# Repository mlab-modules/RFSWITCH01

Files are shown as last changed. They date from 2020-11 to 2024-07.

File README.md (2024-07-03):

# RFSWITCH01 - RF switch

## Introduction

The RFSWITCH01 is an MLAB module that incorporates a pair of RF switches, specifically the [PE4259](http://www.psemi.com/pdf/datasheets/pe4259ds.pdf). from Peregrine Semiconductor. This module is designed to connect to a radio transceiver that has separate radio input and output. Thanks to the use of two switches, the module allows connecting two antennas. The individual switches are controlled by a simple digital input signal. With RFSWITCH01, a transceiver can work with the support of [MIMO 2x2](https://en.wikipedia.org/wiki/MIMO). The module is typically assembled for frequencies of 433MHz and 868MHz.

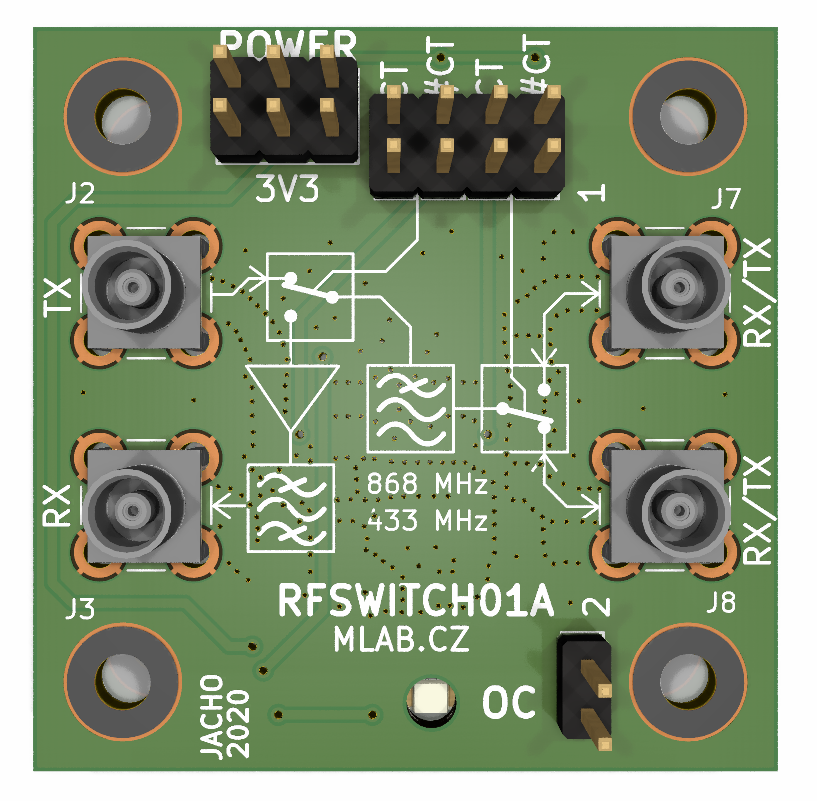
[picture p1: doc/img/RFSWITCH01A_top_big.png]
Top view on RFSWITCH01A


## Key Features and Specifications

- Contains two PE4259 RF switches from Peregrine Semiconductor
- Operating voltage: 1.8V to 3.3V
- Maximum operating frequency: 3GHz
- Low insertion loss (0.35 dB @ 1 Ghz, 0.5 dB @ 2 GHz)
- Operating temperature range: -40°C to 85°C
- Four MCX connectors for connection with the radio and two antennas
- Includes a SAW filter and LNA amplifier at the transceiver input

## Applications

The RFSWITCH01 module can be used in a variety of applications where MIMO 2x2 support is required for a radio transceiver. This includes, but is not limited to:

- Drone communication systems
- Wireless data transmission systems
- Radio communication systems in robotics

## More Information

For more detailed information about the PE4259 RF switch, please refer to the [datasheet](http://www.psemi.com/pdf/datasheets/pe4259ds.pdf).

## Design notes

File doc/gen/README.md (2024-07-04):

# PCB

Board size: 40.13x40.13 mm (1.58x1.58 inches)

- This is the size of the rectangle that contains the board
- Thickness: 1.6 mm (63 mils)
- Material: FR4
- Finish: None
- Layers: 2
- Copper thickness: 35 µm

Solder mask: TOP / BOTTOM

- Color: Top: White / Bottom: Green

Silk screen: TOP / BOTTOM

- Color: Top: Black / Bottom: White

Stackup:

| Name | Type | Color | Thickness | Material | Epsilon_r | Loss tangent |
|---|---|---|---|---|---|---|
| F.SilkS | Top Silk Screen | Black | | | | |
| F.Paste | Top Solder Paste | | | | | |
| F.Mask | Top Solder Mask | White | 10 | | | |
| F.Cu | copper | | 35 | | | |
| dielectric 1 | core | | 1510 | FR4 | 4.5 | 0.020 |
| B.Cu | copper | | 35 | | | |
| B.Mask | Bottom Solder Mask | Green | 10 | | | |
| B.Paste | Bottom Solder Paste  | | | | | |
| B.SilkS | Bottom Silk Screen | White | | | | |

# Important sizes

Clearance: 0.2 mm (8 mils)

Track width: 0.4 mm (16 mils)

- By design rules: 0.12 mm (5 mils)

Drill: 0.3 mm (12 mils)

- Vias: 0.3 mm (12 mils) [Design: 0.2 mm (8 mils)]
- Pads: 1.0 mm (39 mils)
- The above values are real drill sizes, they add 0.1 mm (4 mils) to plated holes (PTH)

Via: 0.45/0.2 mm (18/8 mils)

- By design rules: 0.4/0.1 mm (16/4 mils)
- Micro via: yes [0.2/0.1 mm (8/4 mils)]
- Buried/blind via: yes
- Total: 290 (thru: 290 buried/blind: 0 micro: 0)

Outer Annular Ring: 0.08 mm (3 mils)

- By design rules: 0.08 mm (3 mils)

Eurocircuits class: 6E
- Using min drill 0.2 mm for an OAR of 0.13 mm

# General stats

Components count: (SMD/THT)

- Top: 0/14 (THT)
- Bottom: 30/1 (SMD + THT)

Defined tracks:

- 0.25 mm (10 mils)
- 0.4 mm (16 mils)
- 0.5 mm (20 mils)
- 0.8 mm (31 mils)
- 0.86 mm (34 mils)
- 1.0 mm (39 mils)

Used tracks:

- 0.4 mm (16 mils) (29) defined: yes
- 0.5 mm (20 mils) (60) defined: yes
- 0.8 mm (31 mils) (3) defined: yes
- 0.86 mm (34 mils) (40) defined: yes

Defined vias:

- 0.45/0.2 mm (18/8 mils)
- 0.8/0.4 mm (31/16 mils)

Used vias:

- 0.45/0.2 mm (18/8 mils) (Count: 281, Aspect: 3.6 A) defined: yes
- 0.8/0.4 mm (31/16 mils) (Count: 9, Aspect: 2.0 A) defined: yes

Holes (excluding vias):

- 0.89 mm (35 mils) (16)
- 1.2 mm (47 mils) (4)
- 1.7 mm (67 mils) (16)
- 2.7 mm (106 mils) (1)
- 3.0 mm (118 mils) (4)

Oval holes:

Drill tools (including vias and computing adjusts and rounding):

- 0.3 mm (12 mils) (281)
- 0.5 mm (20 mils) (9)
- 1.0 mm (39 mils) (16)
- 1.3 mm (51 mils) (4)
- 1.8 mm (71 mils) (16)
- 2.7 mm (106 mils) (1)
- 3.1 mm (122 mils) (4)

Solder paste stats:

Using a paste with 87.75 % alloy, that has an specific gravity for the alloy of 7.4 g/cm³
and 1.0 g/cm³ for the flux. This paste has an specific gravity of  4.15 g/cm³.

The stencil thickness is  0.12 mm.

| Side | Pads with paste | Area [mm²] | Paste [g] |
|---|---|---|---|
| Total  | 78 | 92.82 | 0.46 |

Note: this is just an approximation to the theoretical value. Margins of the solder mask and waste aren't computed.

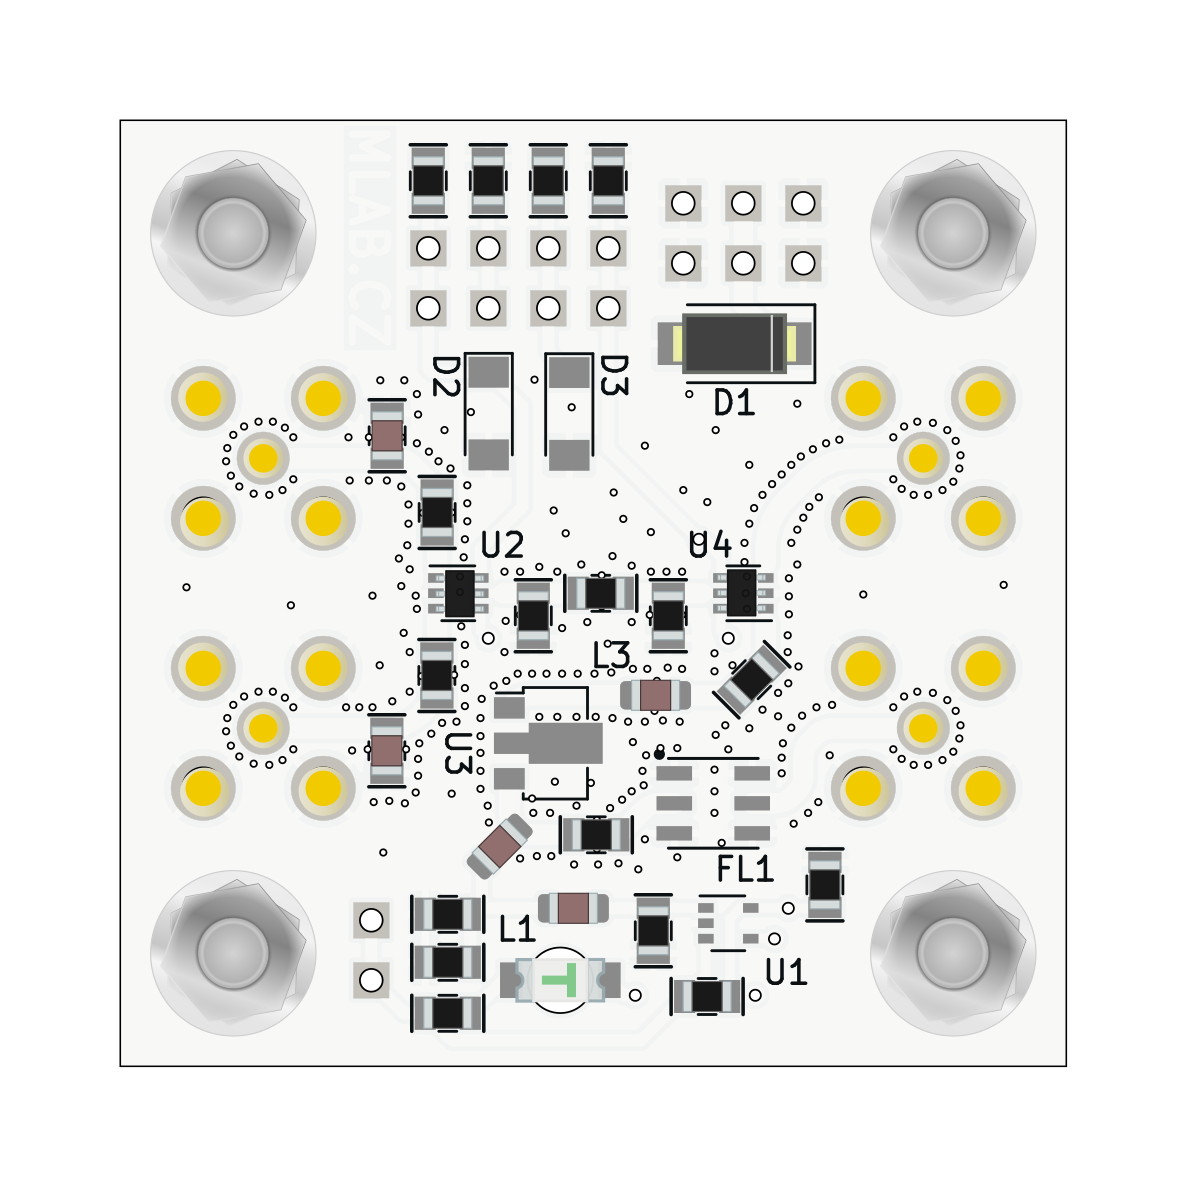
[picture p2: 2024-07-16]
doc/gen/img/RFSWITCH01-bottom.png

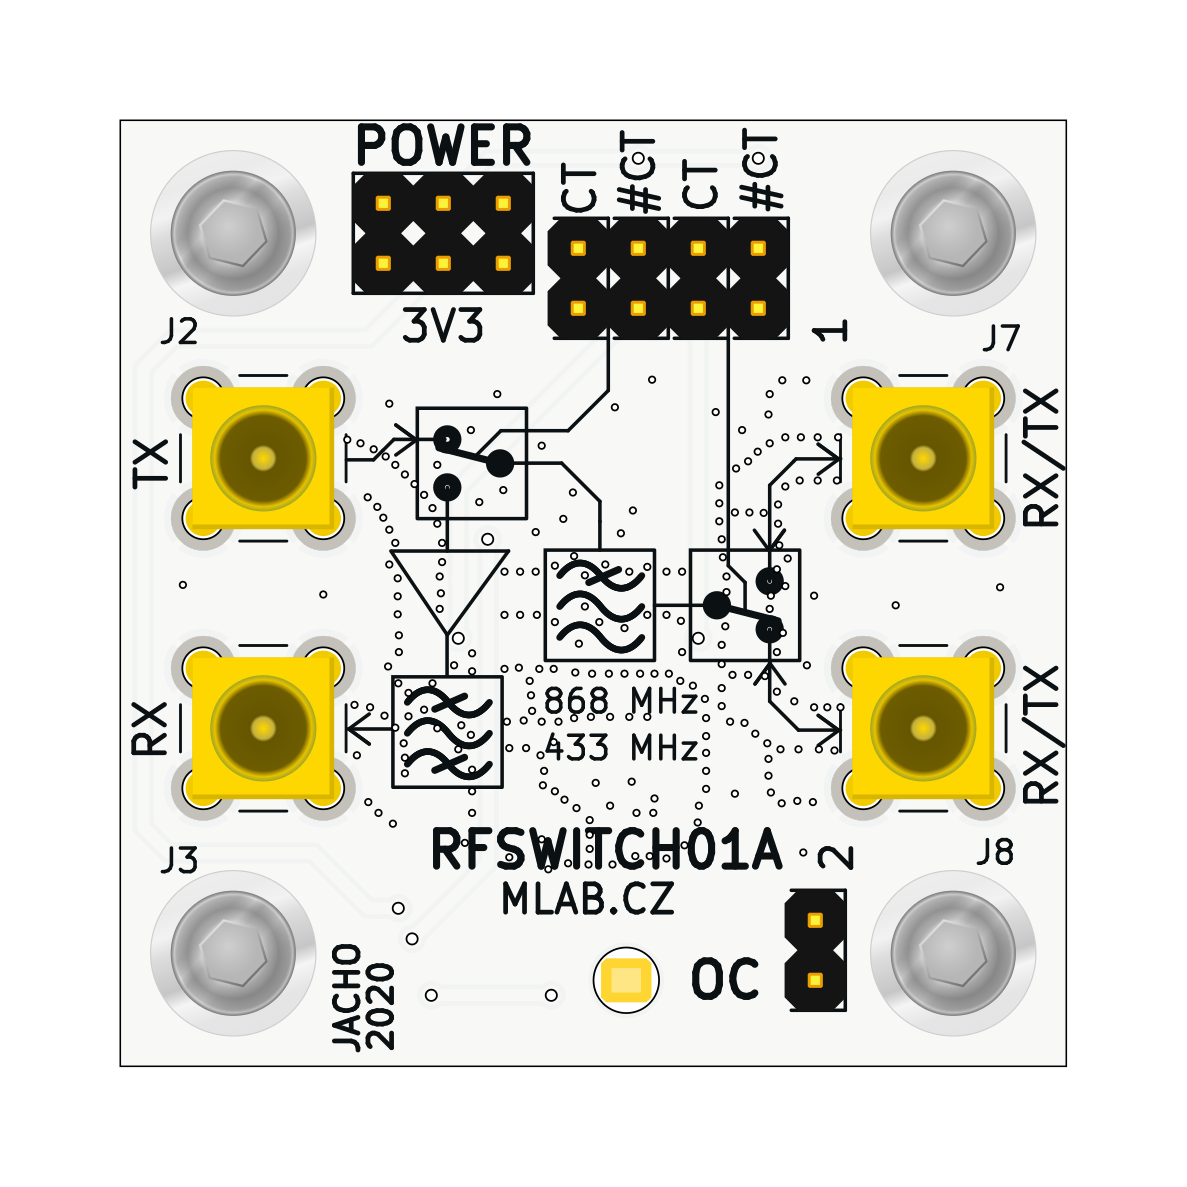
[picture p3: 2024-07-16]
doc/gen/img/RFSWITCH01-top.png

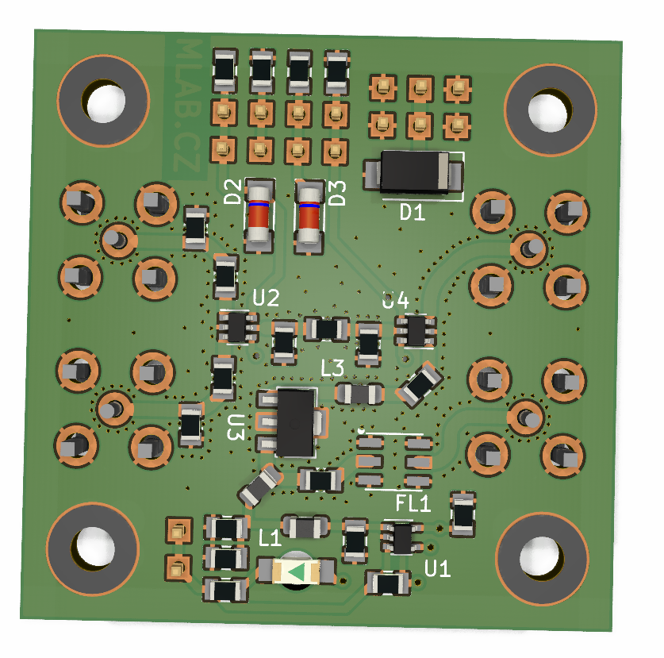
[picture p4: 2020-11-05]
doc/img/RFSWITCH01A_bot_big.png

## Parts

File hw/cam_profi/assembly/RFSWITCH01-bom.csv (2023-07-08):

Component | Description | Part | References | Value | Footprint | Quantity Per PCB | Datasheet | ust_id
1 | Unpolarized capacitor | C | C9C10 | 2p2 | SMD-0805 | 2 | ~ | 5c70984712875079b91f8b27
2 | Unpolarized capacitor | C | C2C4 | 100pF | SMD-0805 | 2 | ~ | 5c70984712875079b91f8b3b
3 | Unpolarized capacitor | C | C5C6C7C8 | 1nF | SMD-0805 | 4 | ~ | 5c70984712875079b91f8b45
4 | Unpolarized capacitor | C | C3 | 100nF | SMD-0805 | 1 | ~ | 5c70984712875079b91f8b4c
5 | Unpolarized capacitor | C | C1 | 10uF | SMD-0805 | 1 | ~ | 5c70984812875079b91f8bbd
6 | Zener diode | D_Zener | D2D3 | BZV55C-3,6V | D_MiniMELF | 2 | https://www.tme.eu/cz/details/mmsz5227bq-7-f/zenerovy-diody-smd/diodes-incorporated/ | 5c70984512875079b91f88b1
7 | Diode | D | D1 | M4 | D_SMA | 1 | ~ | 5c70984512875079b91f88ac
8 | Light emitting diode | LED | D4 | RED | LED_1206 | 1 | ~ | 5c70984412875079b91f8896
9 | Dielectric Band Pass Filter for 1575MHz | SAW_AFS434S3-T_AFS869S3-T | FL1 | SAW_AFS434S3-T_AFS869S3-T | ABRACON_AFS | 1 |  | 5c70984712875079b91f8b19
10 | 2x01 2.54 mm pitch header, 2 pins next to each other are connected | HEADER_2x01_PARALLEL | J4J5J6J9J10 | HEADER_2x01_PARALLEL | Straight_2x01 | 5
11 | 2x03 2.54 mm pitch header, 2 pins next to each other are connected | HEADER_2x03_PARALLEL | J1 | HEADER_2x03_PARALLEL | Straight_2x03 | 1
12 |  | SMA | J2J3J7J8 | SMA | SMB_Jack_Vertical | 4 |  | 5fa10cc512875025b39779f6
13 | Inductor | L | L6 | 6n8 | SMD-0805 | 1 | ~ | 5face69f12875025b3977f1d
14 | Inductor | L | L2L4L5 | 100nH | L_0805_2012Metric | 3 | ~ | 5c70984412875079b91f880a
15 | Inductor | L | L3 | 1n5H | L_0805_2012Metric | 1 | ~ | 5face60a12875025b3977f03
16 | Inductor | L | L1 | 74279204 | L_0805_2012Metric | 1 | ~
17 | Resistor | R | R6 | 330R | SMD-0805 | 1 | ~ | 5c70984512875079b91f8984
18 | Resistor | R | R1R2R3R4R5 | 10k | SMD-0805 | 5 | ~ | 5c70984612875079b91f899f
19 | RF Switch | PE4259 | U2 | PE4259 | SOT-363_SC-70-6 | 1 | https://www.psemi.com/pdf/datasheets/pe4259ds.pdf | 5face19b12875025b3977e15
20 | RF Switch | MLAB_IO:PE4259_1 | U4 | PE4259 | SOT-363_SC-70-6 | 1 | https://www.psemi.com/pdf/datasheets/pe4259ds.pdf | 5face19b12875025b3977e15
21 | 50MHz to 4000MHz, GaAs pHEMT low noise MMIC amplifier, SOT-89 | SPF5189Z | U3 | SPF5189Z | SOT-89-3 | 1 | www.qorvo.com/products/d/da001910 | 5c70984612875079b91f8a08
22 | x Low-input-voltage Current-limited Load Switches With Shut Off And AutoRestart Feature | TPS22945DCKR | U1 | TPS22945DCKR | SOT-353_SC-70-5 | 1 | https://www.ti.com/lit/ds/symlink/tps22945.pdf?HQS=TI-null-null-mousermode-df-pf-null-wwe&ts=1603435443532 | 5c70984612875079b91f89ca

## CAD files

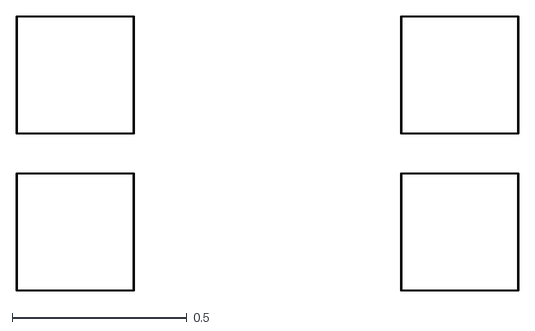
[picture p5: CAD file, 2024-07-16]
doc/gen/dxf/RFSWITCH01-F_Courtyard.dxf
1.44 x 0.787

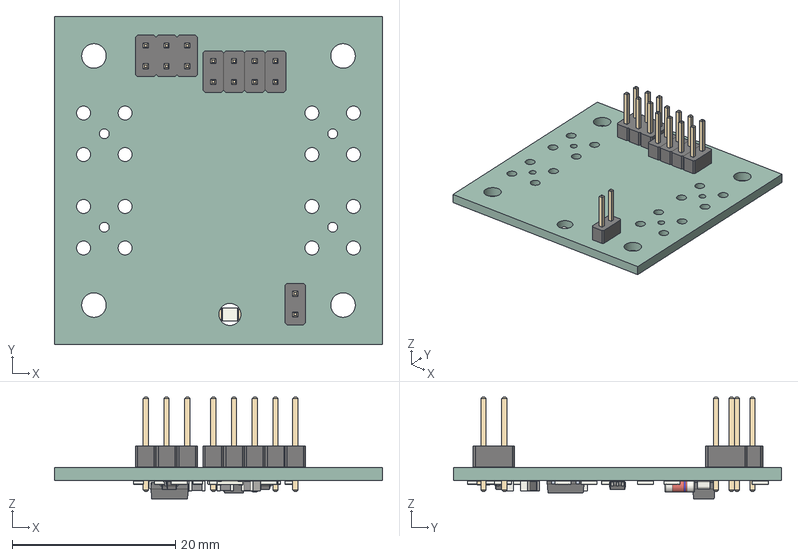
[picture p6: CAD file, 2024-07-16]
doc/gen/RFSWITCH01.step
40.1 x 40.1 x 12.5 mm
PinHeader_2x01_P254mm_Vertical x 5
PinHeader_2x03_P254mm_Vertical
R_0805_2012Metric x 19
D_SMA
SOT_363_SC_70_6 x 2
CQ assembly
D_MiniMELF_Standard x 2
SOT_353_SC_70_5
LED_1206_3216Metric
L_0805_2012Metric x 3
kibot_01qteoe2_PCB

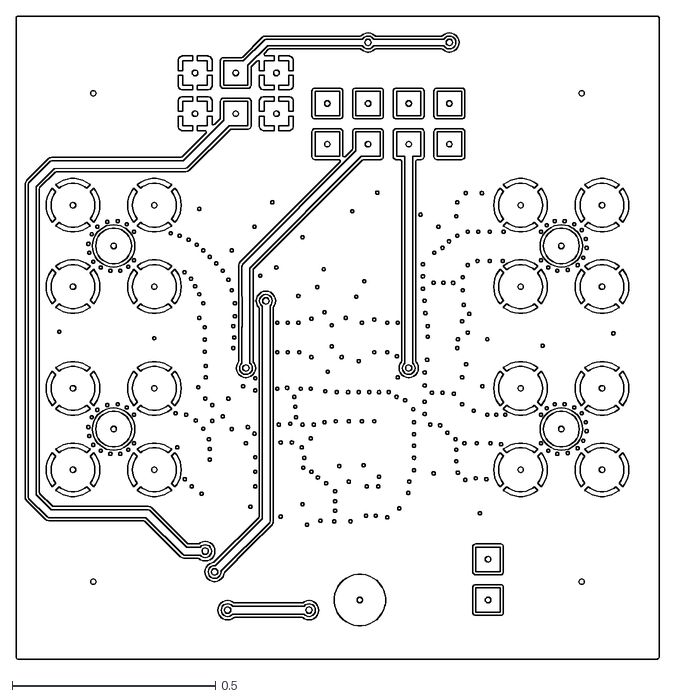
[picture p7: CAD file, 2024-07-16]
doc/gen/dxf/RFSWITCH01-F_Cu.dxf
1.58 x 1.58

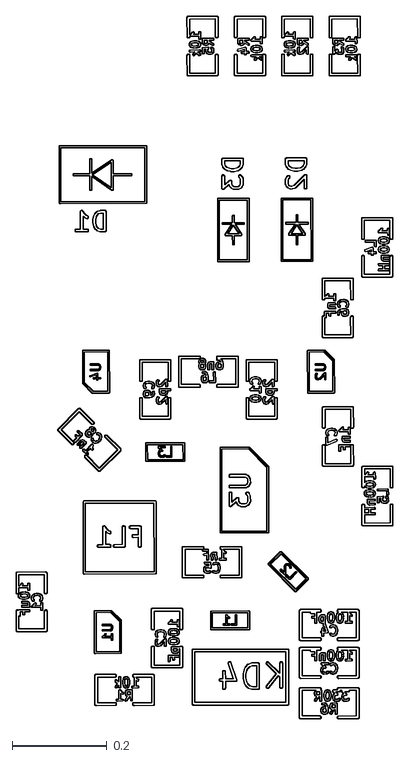
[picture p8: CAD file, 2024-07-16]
doc/gen/dxf/RFSWITCH01-B_Fab.dxf
0.796 x 1.48

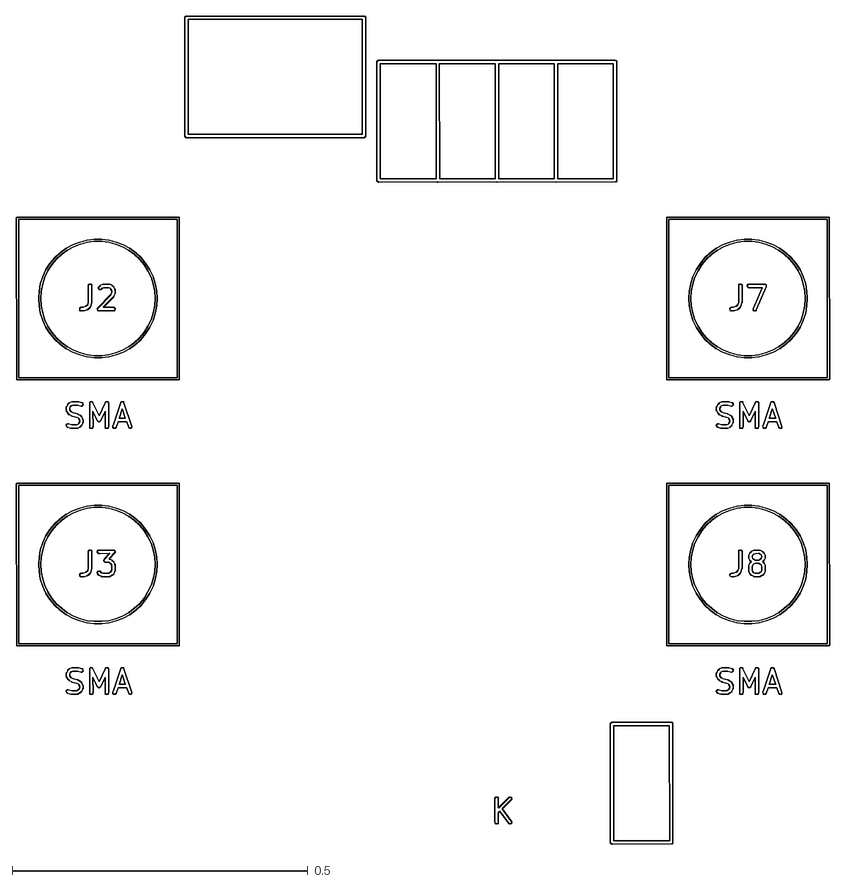
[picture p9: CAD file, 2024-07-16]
doc/gen/dxf/RFSWITCH01-F_Fab.dxf
1.38 x 1.40

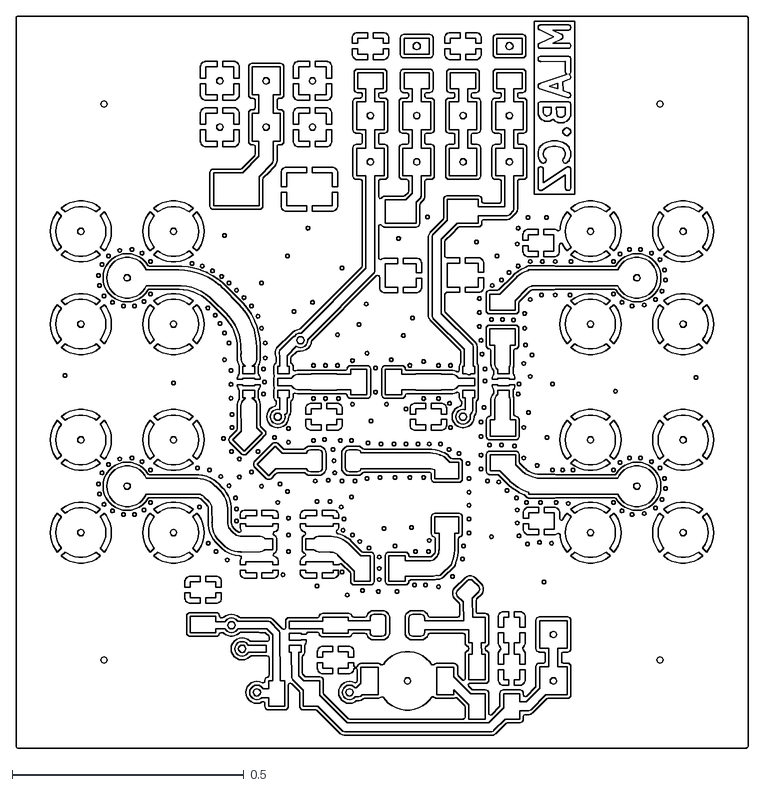
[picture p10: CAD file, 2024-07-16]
doc/gen/dxf/RFSWITCH01-B_Cu.dxf
1.58 x 1.58

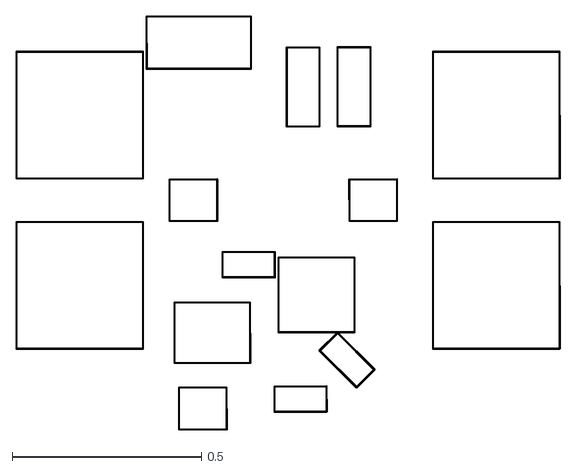
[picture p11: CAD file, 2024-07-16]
doc/gen/dxf/RFSWITCH01-B_Courtyard.dxf
1.44 x 1.09

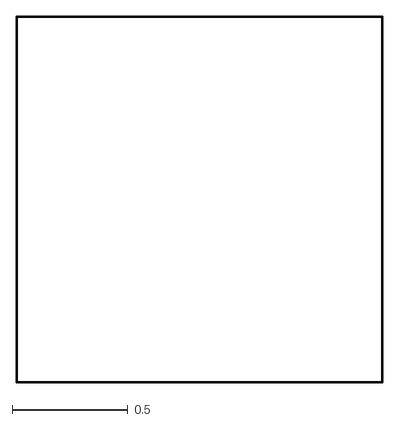
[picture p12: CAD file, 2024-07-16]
doc/gen/dxf/RFSWITCH01-Edge_Cuts.dxf
1.58 x 1.58

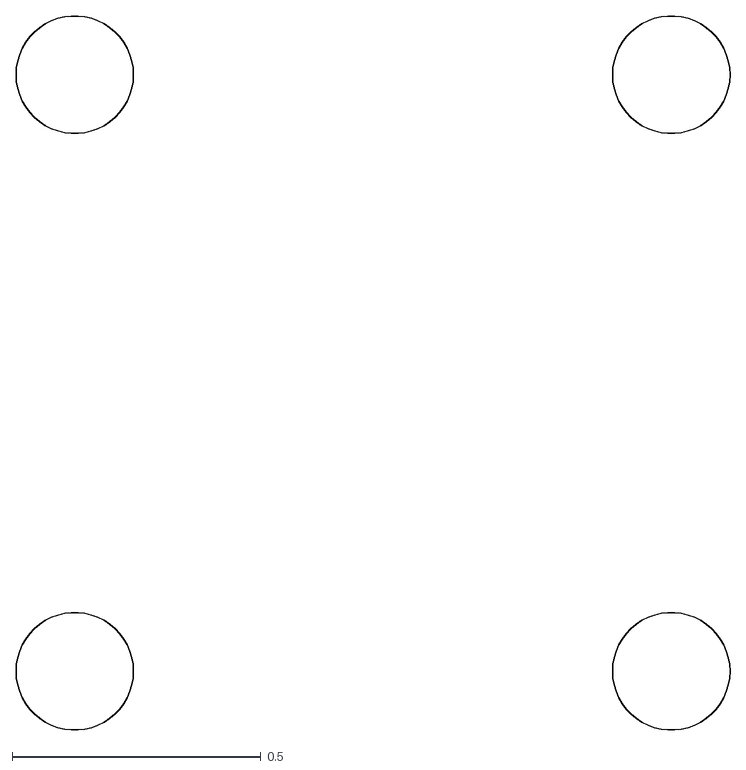
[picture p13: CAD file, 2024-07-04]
doc/gen/dxf/RFSWITCH01-B_Adhesive.dxf
1.44 x 1.44

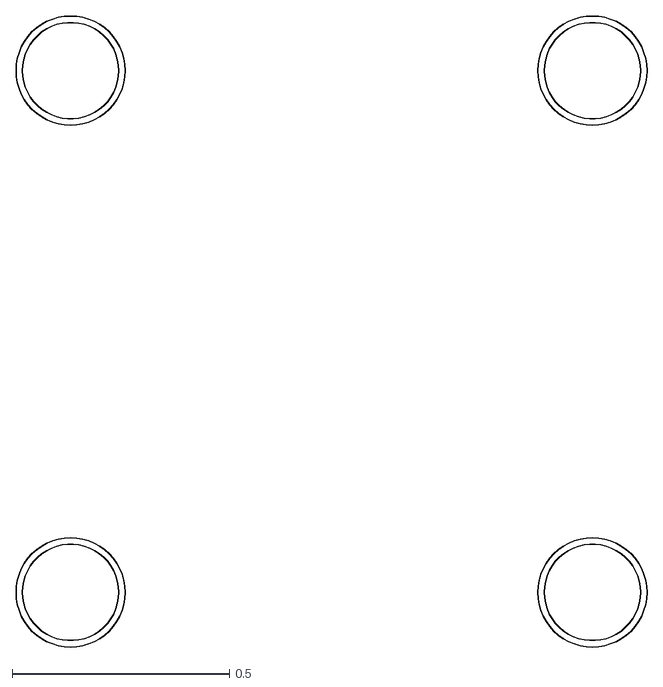
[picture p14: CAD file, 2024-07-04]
doc/gen/dxf/RFSWITCH01-User_Comments.dxf
1.45 x 1.45

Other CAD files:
doc/gen/dxf/RFSWITCH01-User_Eco2.dxf
doc/gen/dxf/RFSWITCH01-User_4.dxf
doc/gen/dxf/RFSWITCH01-User_1.dxf
doc/gen/dxf/RFSWITCH01-Margin.dxf
doc/gen/dxf/RFSWITCH01-User_5.dxf
doc/gen/dxf/RFSWITCH01-User_9.dxf
doc/gen/dxf/RFSWITCH01-User_8.dxf
doc/gen/dxf/RFSWITCH01-B_Mask.dxf
doc/gen/dxf/RFSWITCH01-B_Paste.dxf
doc/gen/dxf/RFSWITCH01-B_Silkscreen.dxf
doc/gen/dxf/RFSWITCH01-F_Mask.dxf
doc/gen/dxf/RFSWITCH01-F_Paste.dxf
doc/gen/dxf/RFSWITCH01-F_Silkscreen.dxf
doc/gen/dxf/RFSWITCH01-User_2.dxf
doc/gen/dxf/RFSWITCH01-User_3.dxf
doc/gen/dxf/RFSWITCH01-User_6.dxf
doc/gen/dxf/RFSWITCH01-User_7.dxf
doc/gen/dxf/RFSWITCH01-User_Drawings.dxf
doc/gen/dxf/RFSWITCH01-User_Eco1.dxf

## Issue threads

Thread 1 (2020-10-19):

RF přepínač

kaklik, 2020-10-19:
Vypadá to že použitelný by měl být  [PE4259](https://www.psemi.com/pdf/datasheets/pe4259ds.pdf)

Alternativou je ještě tenhle [AS193](https://cz.mouser.com/datasheet/2/472/200186C-1524766.pdf)

ChroustJan, 2020-10-21:
Zvolíme PE4259. Pin 6 #

kaklik, 2020-10-21:
> Zvolíme PE4259. Pin 6 #CTRL dame na Vdd?

Myslím že by to mělo být vyvedené na hřebínek, neboť většina těchto přepínačů se ovládá komplementárně. Tenhle je vyjímka, kdybychom to zapojili fixně, tak může být problém s jeho záměnou za jiný typ.

Navíc ještě to napájecí napětí u toho přepínače může být maximálně 3.3 V ale zesilovač z #3 má napájecí napětí i 5V.

Closed 2020-10-23.

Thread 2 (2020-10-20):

SAW filtr

kaklik, 2020-10-20:
Pro modul je potřeba najít SAW filtr, který je možné dát na vstupní RX cestu směrem k modulu ISM01A.
Tím by měla být zvýšena vstupní odolnost modemu.

Vybraný filtr by měl mít stejné pouzdro pro obě základní ISM pásma 433MHz a  868MHz.
Velkou část  thru se SAW filtry do nedávna ovládala firma EPCOS, která byla ale zřejmě koupena firmou TDK a produky EPCOS se nyní staly nedostupné.

## 433MHz

- [B39431B3721U410](https://cz.farnell.com/epcos/b39431b3721u410/filter-saw-433-92mhz/dp/2360864) - pouzdro 3.0 x 3.0 x 1.1 mm

Alternativou je [AFS434S3-T](https://cz.farnell.com/abracon/afs434s3-t/saw-filter-434mhz-smd-6/dp/2849519), který však má insertion loss 2.7 - 4.5 dB - pouzdro 3.8 x 3.8 x 1.5mm.

## 868MHz

- [B39871B3715U410](https://cz.mouser.com/datasheet/2/136/B3715-84099.pdf) - pouzdro 3.0 x 3.0 x 1.1 mm
- [AFS869S3-T](https://cz.farnell.com/abracon/afs869s3-t/filter-saw-869mhz-smd/dp/2467873) - pouzdro 3.8 x 3.8 x 1.5mm

ChroustJan, 2020-10-23:
@kaklik filtry nemají stejná pouzdra. Jak se bude tento stav řešit na PCB?

kaklik, 2020-10-27:
Vybrány filtry AFS869S3-T a AFS434S3-T.

Closed 2020-10-27.

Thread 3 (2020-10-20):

Vstupní zesilovač

kaklik, 2020-10-20:
Vhodné
- [SPF5189Z](https://eu.mouser.com/ProductDetail/Qorvo/SPF5189Z?qs=p6lVfQR1GSoxtfscJmmzLQ==)

Lze zapojit podle [modemu z balonu](https://github.com/ODZ-UJF-AV-CR/balon/blob/master/HW/transceiver_M1_1_2016/Modem-Modem.pdf):

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

Ve schéma balonového transceiveru je pro vypínání zesilovače použita [proudová pojistka](https://cz.mouser.com/ProductDetail/Texas-Instruments/TPS22945DCKR?qs=IDSsxkoac0yt8oAd7q17%2FA%3D%3D), která je ovládana pinem transceiveru.

To není  vůbec špatný nápad, neboť zesilovač je vhodné vypínat, aby při vysílání nemohlo dojít k poškození přijímače.

V datasheetu píšou něco o možnosti nastavovat pracovní proud, zároveň tam ale nevidím žádné schéma, které by tuhle možnost popisovalo. Je tak možné že proudová pojistka v zapojení modemu balonu ve skutečnosti funguje jako zdroj proudu.  Zesilovač je v tomto případě napájen z 3.3V napájecího napětí.

ChroustJan, 2020-10-30:
Aplikováno

ChroustJan, 2020-10-31:
@kaklik  mohl by jsi definovat stavy, které tam mají být při nezapojeném modulu? Ideálně i kam se má připojit ON.

kaklik, 2020-10-31:
Základní neřízený stav by měl být:

1. Vypnutý vstupní zesilovač - ON  v log 0.
2. RF Přepínač přepnutý na vysílání

Z toto vyplývá že ON musí být připojen na přepinači na signál, který odpovídá stavu log 0, pro vysílání a stavu log 1 pro příjem. Což je podle [datasheetu](https://www.psemi.com/pdf/datasheets/pe4259ds.pdf) zřejmě signál CTRL na pinu 4.

RF vstup zesilovače pak také musí být připojen na odpovídající RF výstup, což je RF1.  Změna je poměrně komplikovaná, takže jsem ji rovnou provedl ve schéma.

Spínač má i tepelnou ochranu. Aby tahle funkce dávala smysl, tak by spínač měl být umístěn v blízkosti zesilovače. (Tepelná ochrana spíná přibližně při 140 deg C).

ChroustJan, 2020-11-01:
Předělán PCB. Spínač nebylo možné umístit přímo k LNA. Přednost dostala RF část.

Closed 2020-11-01.

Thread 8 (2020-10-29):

RF layout

kaklik, 2020-10-29:
Na desce jsem si všiml nepříjemných přechodů tvaru "bočních stěn" mikropáskových vedení. Výrazné je to zejména u konektorů.

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

Zde by bylo potřeba, aby měď byla vylitá spojitě po obou stranách RF cesty - Ta šířka cesty a izolační mezera je teď nějak napočítaná a vychází to zrovna takhle blbě?

Dále se taky snažím zjistit, zda KiCAD umí zaoblené cesty - zvýšilo by to kvalitu a odstranilo možnost vzniku odrazů.

ChroustJan, 2020-10-30:
Provedena optimalizace - řeší jen vylitou zem kolem celých RF cest

kaklik, 2020-10-30:
@ChroustJan  Víš to, že v tom návrhu jsou použity via s vrtáním 0.15mm?

ChroustJan, 2020-10-30:
@kaklik  to je nějaký problém?

kaklik, 2020-10-30:
Je to úplně na hranici vyrobitelnosti. Předpokládám, že to zbytečně zdraží následnou výrobu.

Zaoblené cesty se v novém KiCADu dělají takhle:

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

Menu se otevře po vybrání dvou úseků a volbou "Fillet Tracks" na pop-up menu pravého tlačítka myši.

ChroustJan, 2020-10-30:
Být 50% nad limitem říkáš na hraně? Kolik by jsi tam dal? Volil jsem to malé, aby se to tam vešlo.

ChroustJan, 2020-10-31:
Parametry POOL servisu Gatemy.
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

Teď nevím zda KiCad má výslednou díru, nebo průměr vrtáku. Každopádně si to můžeme pojistit tím že tam dáme tedy 0,2mm a bude to jistota. A minimální průměr toho CU okruží by tedy měl být 0,45. Tohle by mohli být parametry pro zemnící VIA. Ostatní dávám 0,4 a 0,8mm aby jsme měli jistotu.

kaklik, 2020-10-31:
Ok, průměr vias ale nebyl hlavním předmětem tohoto issue.
Důležitá je ta optimalizace RF layoutu, která souvisí například s tím zaoblením RF cest.

kaklik, 2020-11-01:
Vyzkoušel jsem si to trochu zlepšit ten layout. Řekl bych že ta správná cesta vypadá nějak takhle:

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

Ty pozice součástek a tak, by zřejmě asi chtělo trošku daladit.

Potíž, na kterou jsem přitom přišel je ale tohle:

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

Není mi jasné na základě čeho je zvolena ta součastá šířka RF spojů, která je tam použita.

ChroustJan, 2020-11-02:
@kaklik  jednou jsem tu cestu spočítal a používám jí všude na 2V. Tenkrát jsme i získávali nějaké informace od našich dodavatelů. Tak jsem to vyhodnotil, jako přesnější výpočet.

kaklik, 2020-11-03:
Chybí tam ještě via fencig okolo RF cest.

ChroustJan, 2020-11-04:
Přidány via

ChroustJan, 2020-11-05:
@kaklik je to hotové?

kaklik, 2020-11-05:
Teď už si myslím, že je.

Closed 2020-11-06.

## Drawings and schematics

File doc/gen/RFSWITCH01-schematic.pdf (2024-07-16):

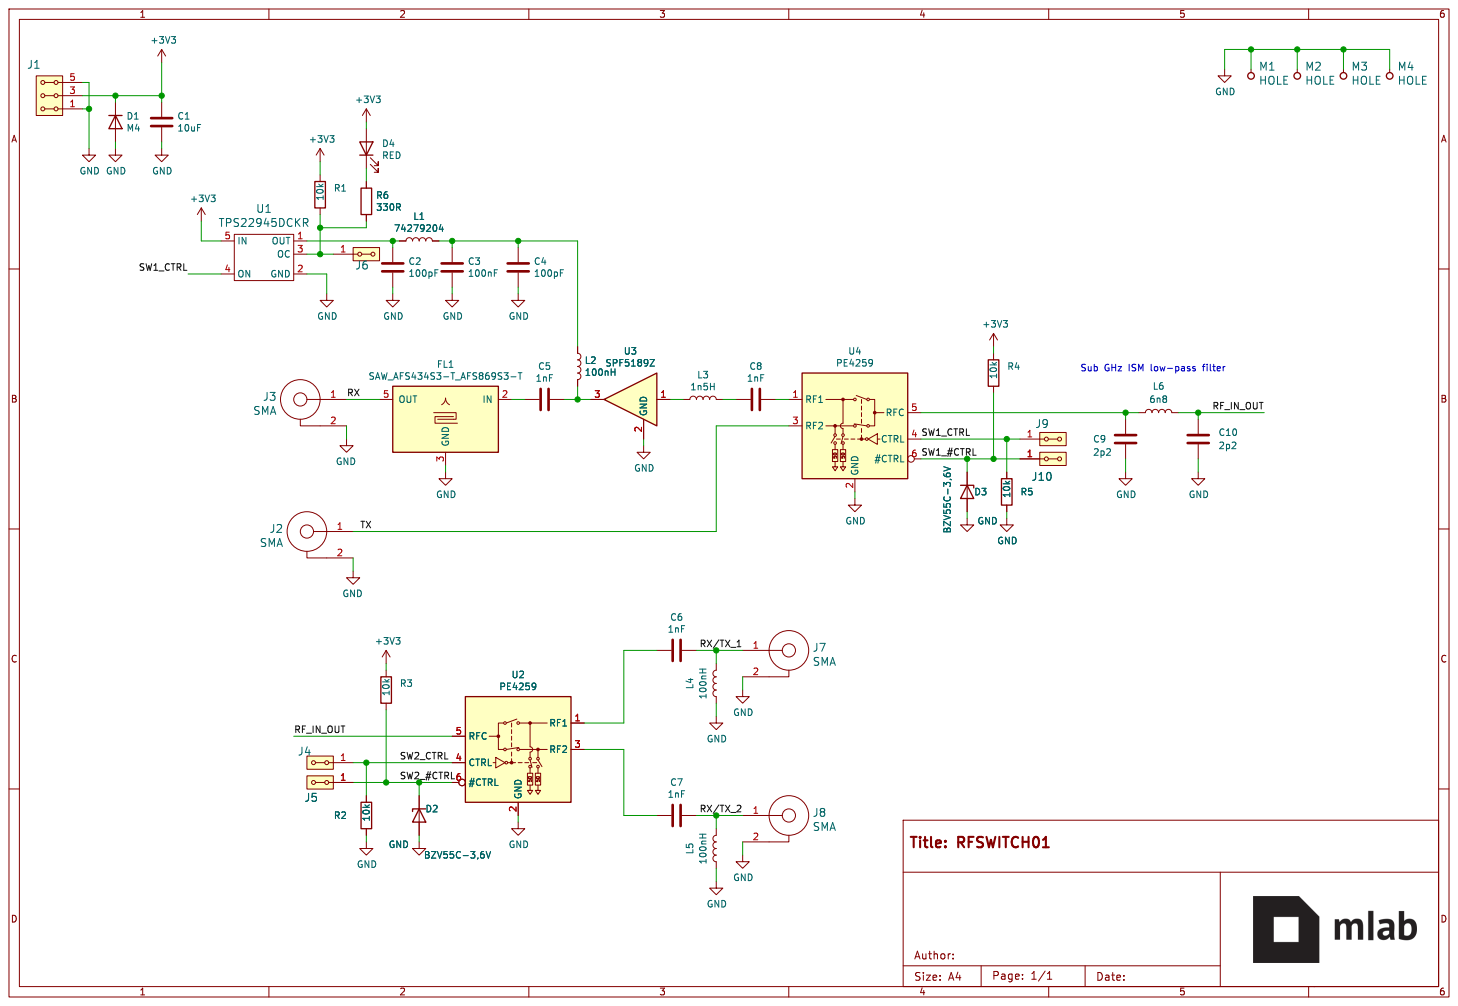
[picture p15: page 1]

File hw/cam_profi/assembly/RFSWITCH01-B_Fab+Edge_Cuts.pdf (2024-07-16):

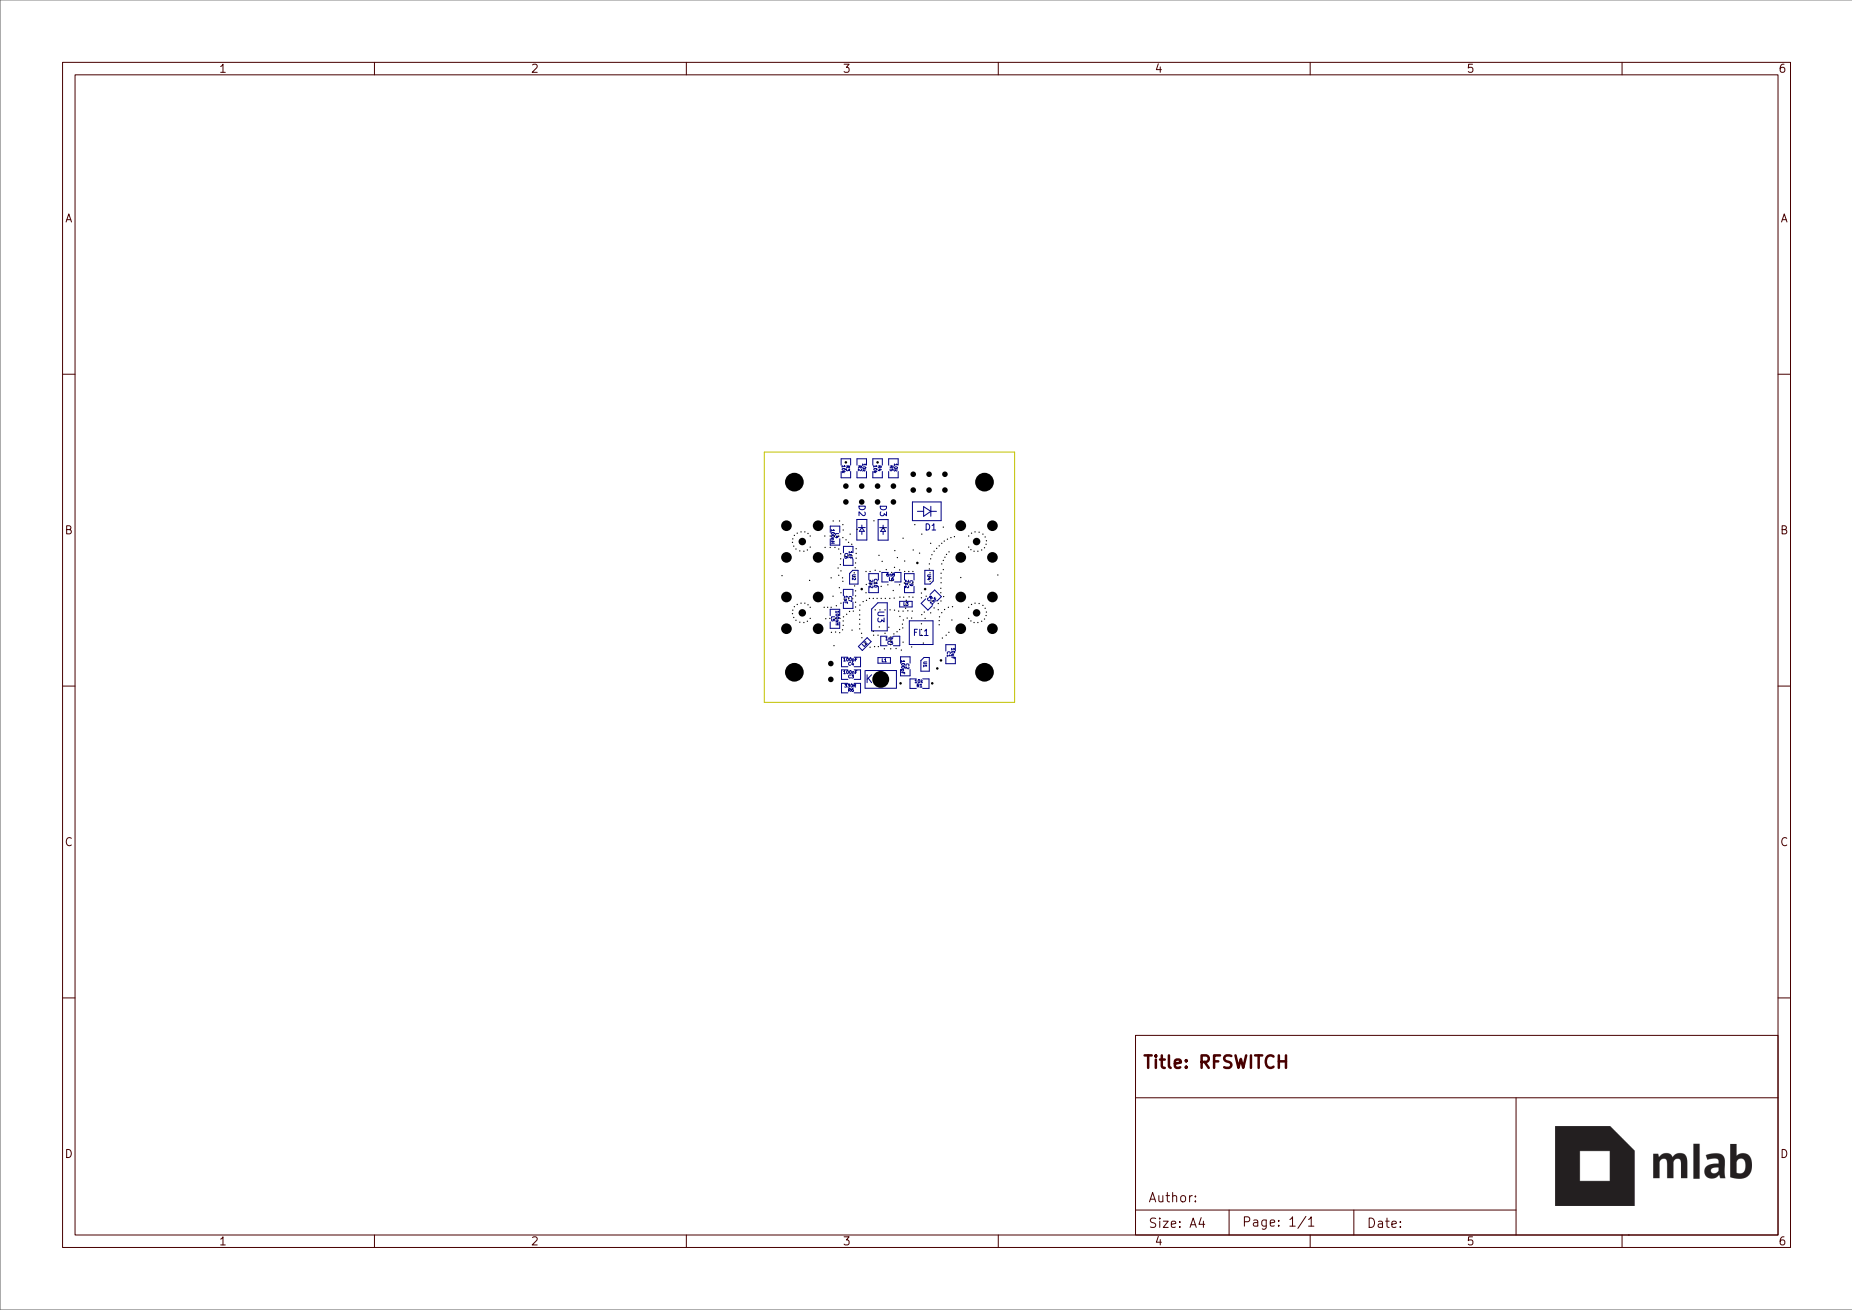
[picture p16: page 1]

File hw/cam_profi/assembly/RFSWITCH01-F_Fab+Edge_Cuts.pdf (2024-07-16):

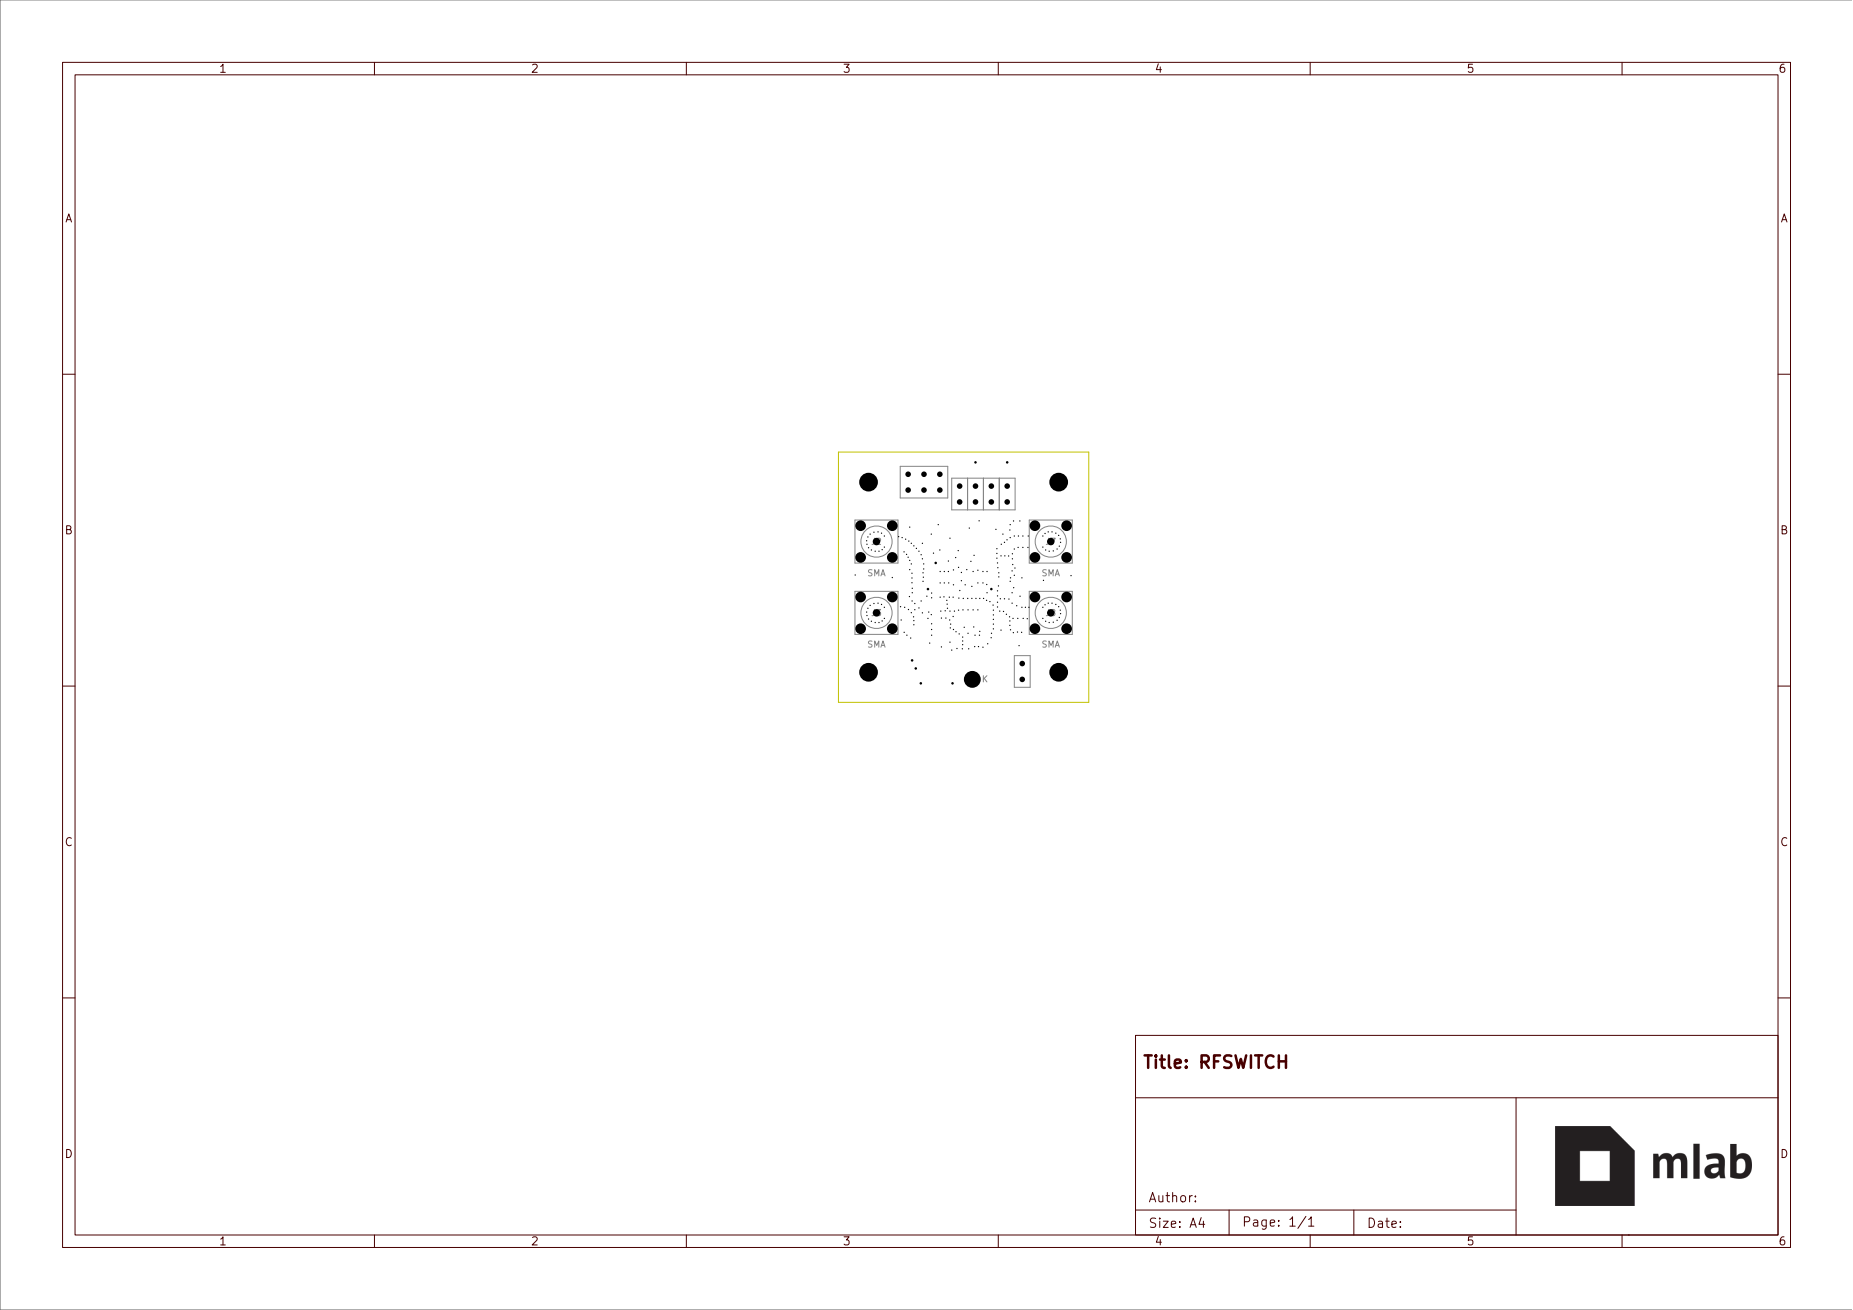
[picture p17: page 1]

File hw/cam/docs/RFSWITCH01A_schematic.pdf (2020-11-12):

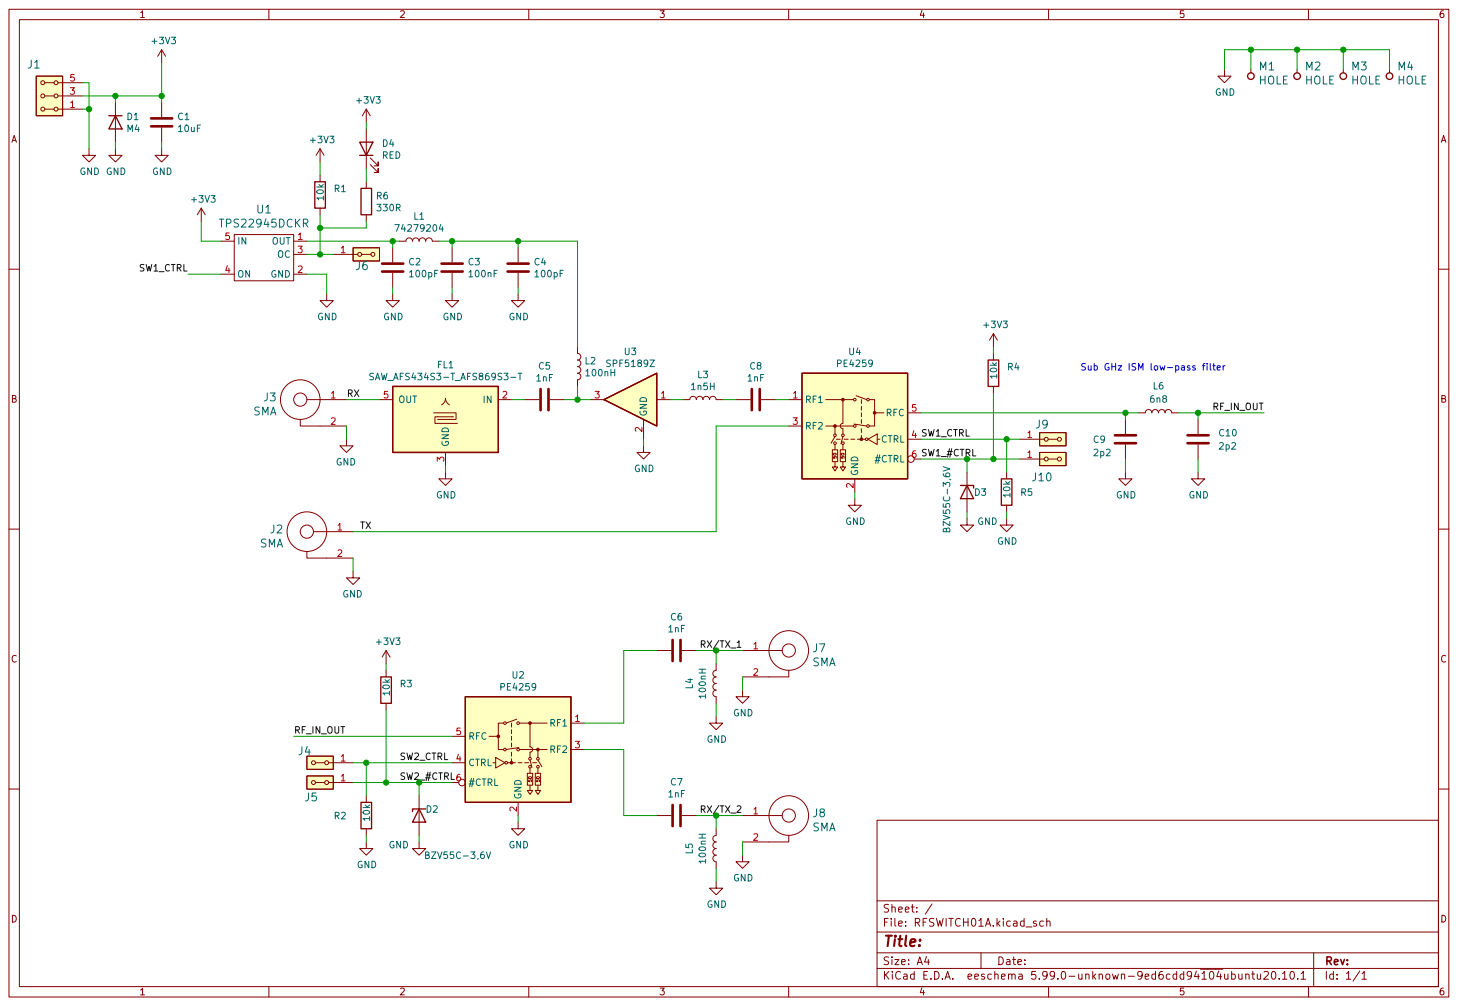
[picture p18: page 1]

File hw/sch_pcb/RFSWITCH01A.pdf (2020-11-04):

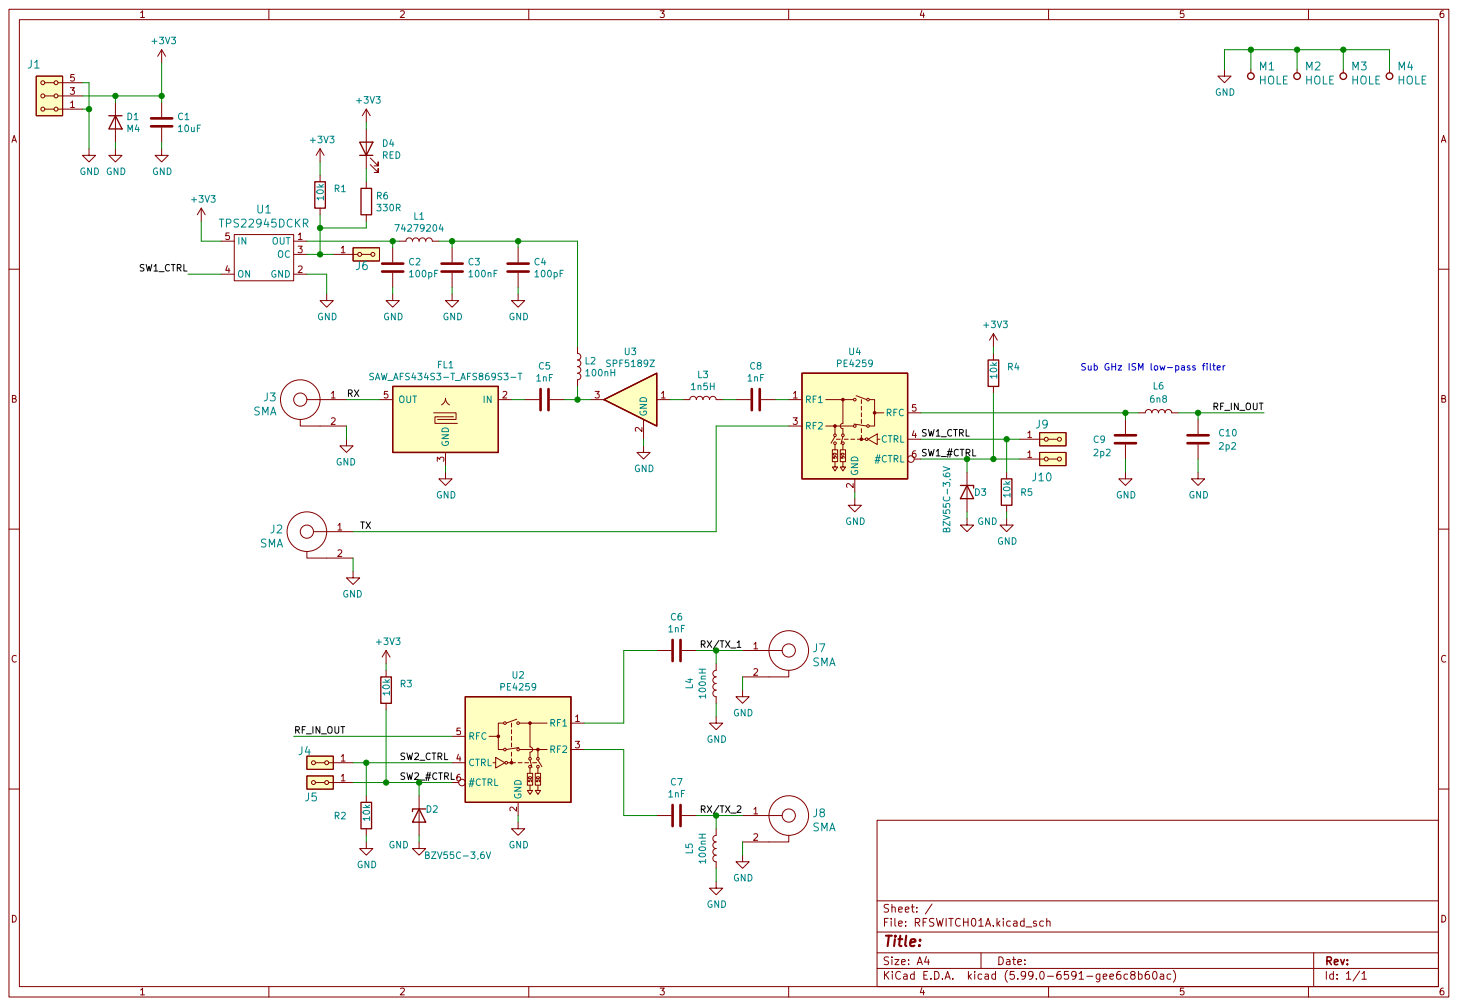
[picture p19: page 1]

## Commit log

2020-10-23 Edit schema
    [RFSWITCH01A.kicad_pcb, RFSWITCH01A.kicad_sch]
2020-10-23 Add datasheet to current limit switch.
    [RFSWITCH01A.kicad_sch]
2020-10-23 Add header on over-current signal.
    [RFSWITCH01A.kicad_sch]
2020-10-27 KiCAD version updated.
    New documentation and cleanup.
    [RFSWITCH01A.kicad_sch]
2020-10-30 Improve layout.
    [RFSWITCH01A.kicad_pcb]
2020-10-30 The first experiment with fillet tracks.
    [RFSWITCH01A.kicad_pcb]
2020-10-30 Edit PCB
    [RFSWITCH01A.kicad_pcb]
2020-10-31 Control signal of AMP directly connected to signal switch.
    Low pass Pi filter between input and output switch.
    RF high-pass shunt protection on antenna input.
    [RFSWITCH01A.kicad_sch]
2020-10-31 Předělávání PCB
    [RFSWITCH01A.kicad_pcb, RFSWITCH01A.kicad_sch]
2020-11-01 Předělání PCB po změně schéma.
    [RFSWITCH01A.kicad_pcb, RFSWITCH01A.kicad_sch]
2020-11-01 Layout improvement #8.
    [RFSWITCH01A.kicad_pcb]
2020-11-03 Silkscreen improvement #6
    [RFSWITCH01A.kicad_pcb]
2020-11-04 Diode, via, 3D model
    [RFSWITCH01A.kicad_pcb, RFSWITCH01A.kicad_sch]
2020-11-04 slight improvement of via shielding.
    [RFSWITCH01A.kicad_pcb]
2020-11-05 Add shielding vias.
    [RFSWITCH01A.kicad_pcb]
2020-11-05 Fix DRC errors.
    [RFSWITCH01A.kicad_pcb]
2020-11-05 Cleanup vias in silksceen.
    [RFSWITCH01A.kicad_pcb]
2020-11-05 Cleanup silkscreen.
    [RFSWITCH01A.kicad_pcb]
2020-11-05 Generovani dat
    [RFSWITCH01A-B_Cu.gbr, RFSWITCH01A-B_Mask.gbr, RFSWITCH01A-Edge_Cuts.gbr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]
2020-11-09 Volba součástek
    [RFSWITCH01A.kicad_sch]
2022-04-06 Update actions products
    [RFSWITCH01A-B_Cu.gbr, RFSWITCH01A-B_Mask.gbr, RFSWITCH01A-Edge_Cuts.gbr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]
2023-07-05 automated commit; rename source files to new naming convence
    [RFSWITCH01.kicad_pcb, RFSWITCH01.kicad_sch]
2023-07-05 update kicad
    [RFSWITCH01.kicad_pcb, RFSWITCH01.kicad_sch]
